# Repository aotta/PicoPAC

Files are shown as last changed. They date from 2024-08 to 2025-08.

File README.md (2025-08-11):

# PicoPAC v.1.0b
Flashcart for Videopac / Odyssey 2 based on Wilco2009 Videopac-microSD card project
Based on SD card by Wilco2009: https://github.com/wilco2009/Videopac-micro-SD-Cart , my greetings for his fantastic job!

Since now, tested on  G-7000, G7400, C52, JOPAC and Odyssey 2. Waiting for a friend that has to repair his G7200 for completing the list ;) 

--changelog v.1.0a ->
Added support to extROM games too (VP_40 and VP_31).
Added filename reading from flash (max files read = 25*8) 

--changelog v.1.0b ->
fixed KTAA final rom

Other info also on Nightfallcrew blog: https://www.nightfallcrew.com/22/09/2024/flash-multicart-for-philips-videopac-magnavox-odyssey-2/

PicoPAC is a multicart DIY yourself based on cheap "PURPLE" Raspberry Pi Pico clone, easy to build and not expensive.
**WARNING!** "purple" Pico has not the same pinout of original Raspberry "green" ones, you MUST use the clone or you may damage your hardware.

**NOTE** You should find all the ROM following this site https://rene-g7400.datatex.nl/ 
Please don't forget to upload the here provided "selectgame.bin" and "selectgame.$$$" file in flash!!!!
Also, even if now you can change filenames, remember that extROM games are checked by name, so they works only if named "VP_31.bin", "VP_40.bin" or "4inarow.bin"!

**NOTE 2** 3D files for shell are WIP and probably the PCB doesn't fit perfectly withous some cut/drill to PCB holes!! (Thanks to Mike Wilson for the Logo version)

Added alternate STLs files thanks to kokkiklhs (see https://forums.atariage.com/topic/370606-picopac-a-pico-purple-porting-of-videopac-microsdcard/page/4/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 for further details)

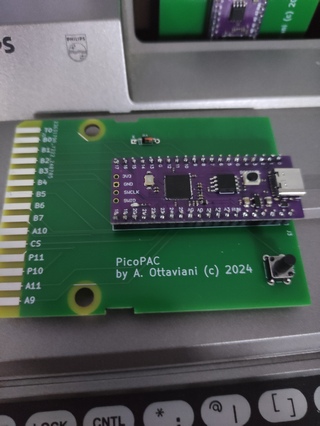
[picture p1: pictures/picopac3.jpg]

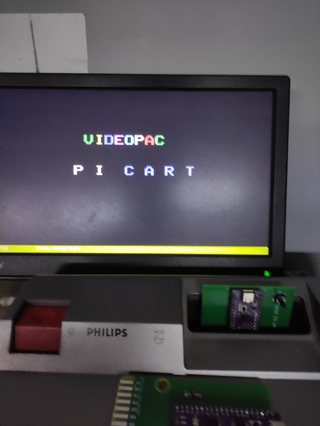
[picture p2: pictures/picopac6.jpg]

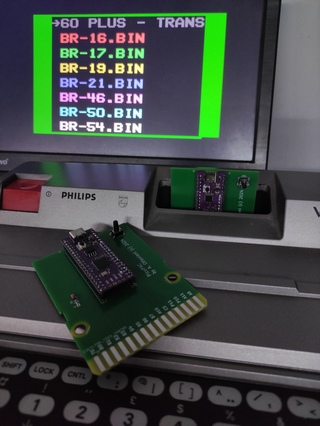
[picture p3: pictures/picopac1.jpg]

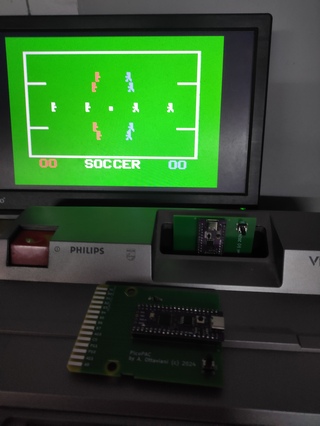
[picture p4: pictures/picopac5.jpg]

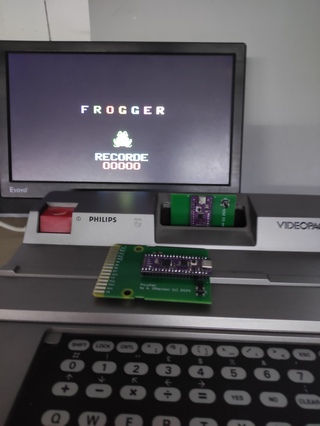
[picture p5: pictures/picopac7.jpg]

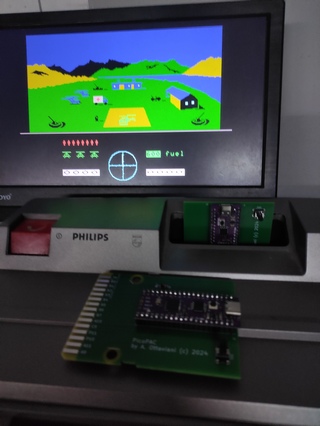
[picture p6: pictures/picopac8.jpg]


Kicad project and gerbers files for the pcb are in the PCB folder, you need only a diode and a push buttons for resetting the cart if needed or want restart. 
Add you pico clone, and flash the firmware ".uf2" in the Pico by connecting it while pressing button on Pico and drop it in the opened windows on PC.
After flashed with firmware, and every time you have to change your ROMS repository, you can simply connect the Pico to PC and drag&drop "BIN" files  into.
But remember that only games already in menu will be seen by the cart.

Even if the diode should protect your console, **DO NOT CONNECT PICO WHILE INSERTED IN A POWERED ON CONSOLE!**

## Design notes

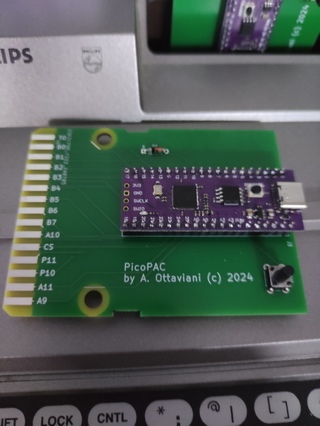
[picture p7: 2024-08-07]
pictures/picopac4.jpg

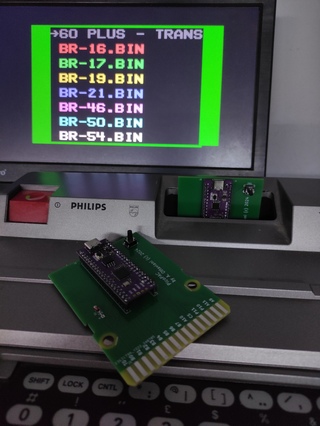
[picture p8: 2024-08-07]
pictures/picopac2.jpg

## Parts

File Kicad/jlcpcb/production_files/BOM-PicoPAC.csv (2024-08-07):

Comment | Designator | Footprint | LCSC
Conn_01x20 | J3 | PinSocket_1x20_P2.54mm_Vertical
Conn_01x20 | J2 | PinSocket_1x20_P2.54mm_Vertical
SW_Push | SW1 | SW_PUSH_6mm
Diode | D1 | D_DO-35_SOD27_P7.62mm_Horizontal
Videopac-edgeconnector | J1 | videopac-edgecon

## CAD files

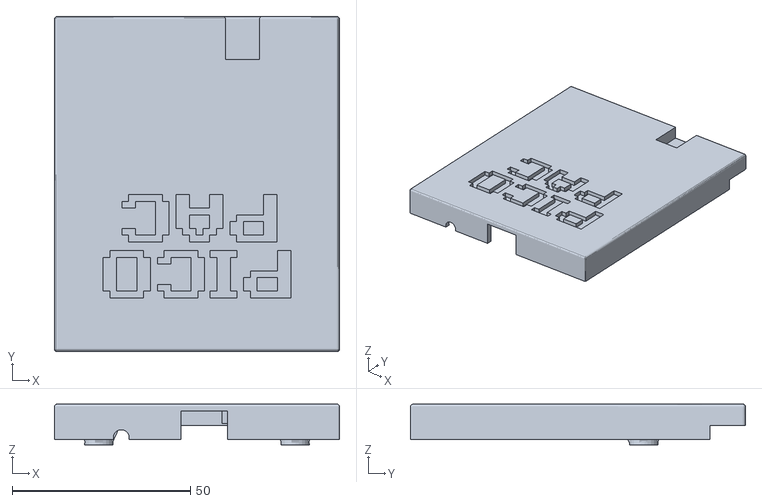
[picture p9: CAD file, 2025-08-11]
3dPrint/Alternate/PicoPAC_1.stl
80.0 x 94.0 x 11.5

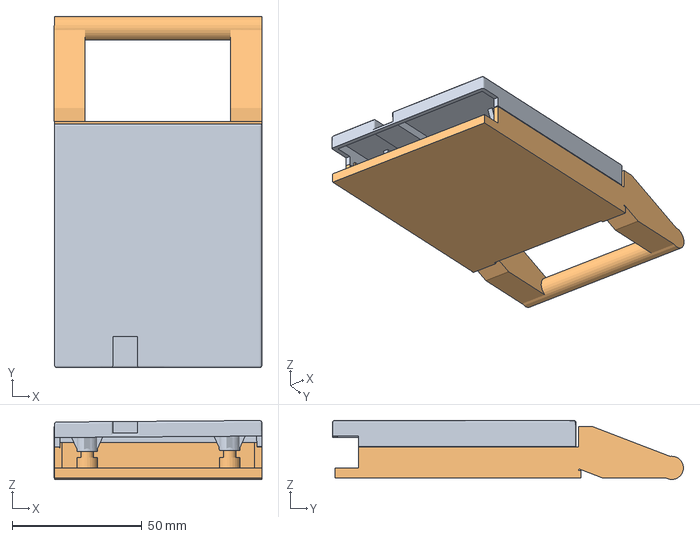
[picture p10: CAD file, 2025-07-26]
3dPrint/PicoPAC.FCStd
80.3 x 135.5 x 22.8 mm
PicoPAC_top-Cover (Meshed)
Base (Meshed)

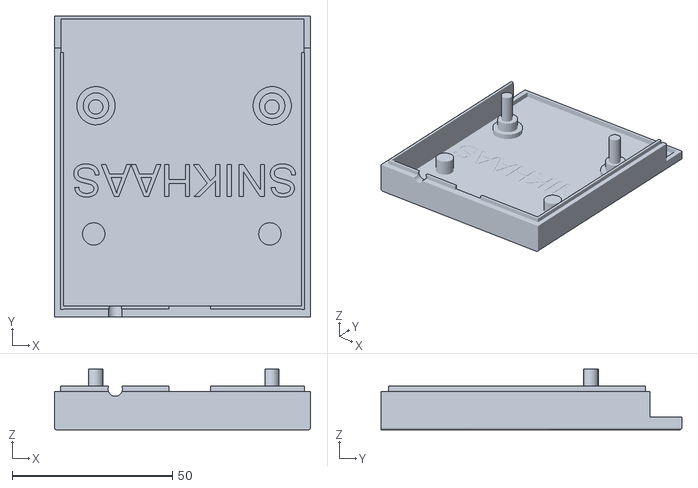
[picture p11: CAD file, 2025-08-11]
3dPrint/Alternate/PicoPAC_2.stl
80.0 x 94.0 x 19.0

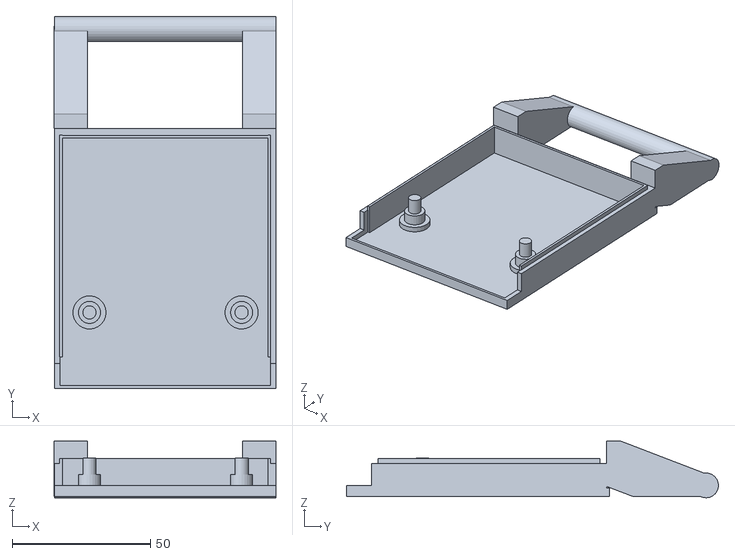
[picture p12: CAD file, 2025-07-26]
3dPrint/PicoPAC-Base (Meshed).stl
80.2 x 134.5 x 20.5

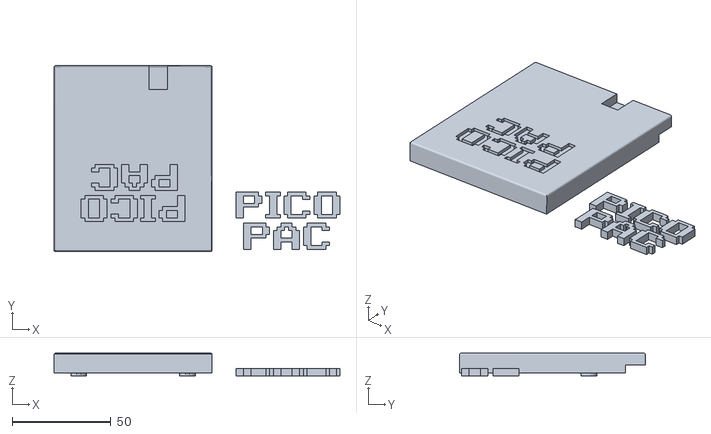
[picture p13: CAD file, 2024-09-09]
3dPrint/o2picocartlogo2.stl
144.7 x 94.0 x 11.5

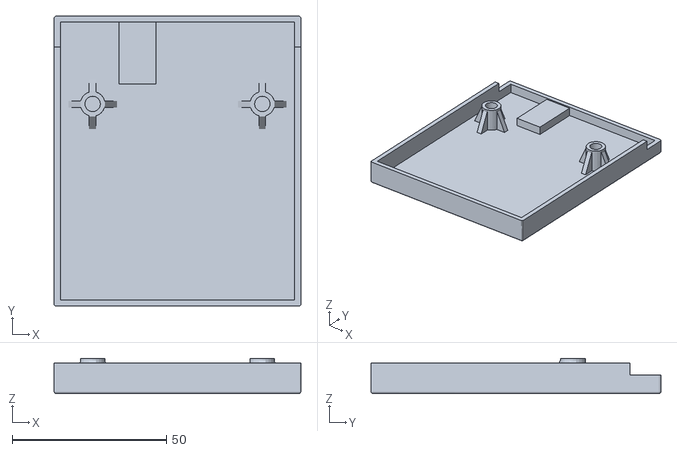
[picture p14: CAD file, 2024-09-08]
3dPrint/PicoPAC_top-Cover (Meshed).stl
80.0 x 94.0 x 11.5

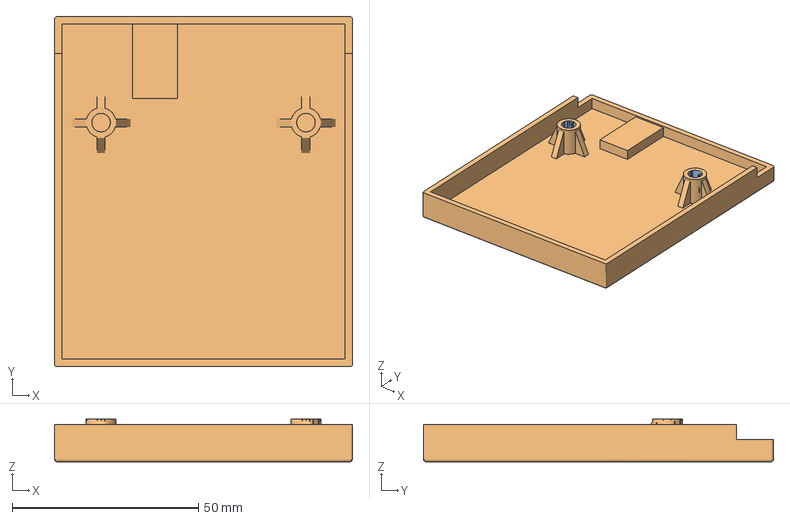
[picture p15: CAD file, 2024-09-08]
3dPrint/PicoPAC_top.FCStd
80.0 x 94.0 x 11.5 mm
Cover
Cover (Meshed)

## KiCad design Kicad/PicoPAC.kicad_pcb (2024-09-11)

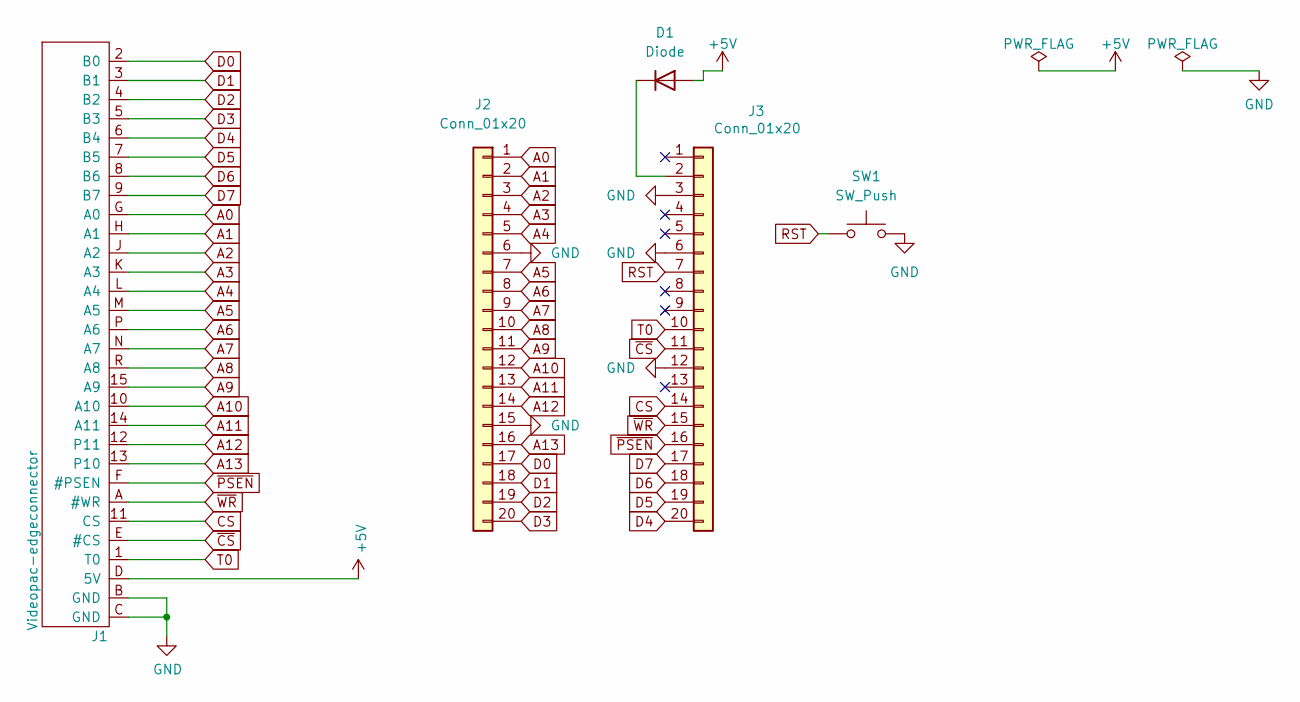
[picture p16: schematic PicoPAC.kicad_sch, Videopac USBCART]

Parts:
D1: Diode; D_DO-35_SOD27_P7.62mm_Horizontal
J1: Videopac-edgeconnector; videopac-edgecon
J2, J3: Conn_01x20; PinSocket_1x20_P2.54mm_Vertical
SW1: SW_Push; SW_PUSH_6mm

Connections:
+5V: D1.2 (A), J1.D (5V)
A0: J1.G (A0), J2.1
A1: J1.H (A1), J2.2
A2: J1.J (A2), J2.3
A3: J1.K (A3), J2.4
A4: J1.L (A4), J2.5
A5: J1.M (A5), J2.7
A6: J1.P (A6), J2.8
A7: J1.N (A7), J2.9
A8: J1.R (A8), J2.10
A9: J1.15 (A9), J2.11
A10: J1.10 (A10), J2.12
A11: J1.14 (A11), J2.13
A12: J1.12 (P11), J2.14
A13: J1.13 (P10), J2.16
CS: J1.11 (CS), J3.14
D0: J1.2 (B0), J2.17
D1: J1.3 (B1), J2.18
D2: J1.4 (B2), J2.19
D3: J1.5 (B3), J2.20
D4: J1.6 (B4), J3.20
D5: J1.7 (B5), J3.19
D6: J1.8 (B6), J3.18
D7: J1.9 (B7), J3.17
GND: J1.B (GND), J1.C (GND), J2.6, J2.15, J3.3, J3.6, J3.12, SW1.2
unnamed: D1.1 (K), J3.2
RST: J3.7, SW1.1
T0: J1.1 (T0), J3.10
~CS: J1.E (#CS), J3.11
~PSEN: J1.F (#PSEN), J3.16
~WR: J1.A (#WR), J3.15

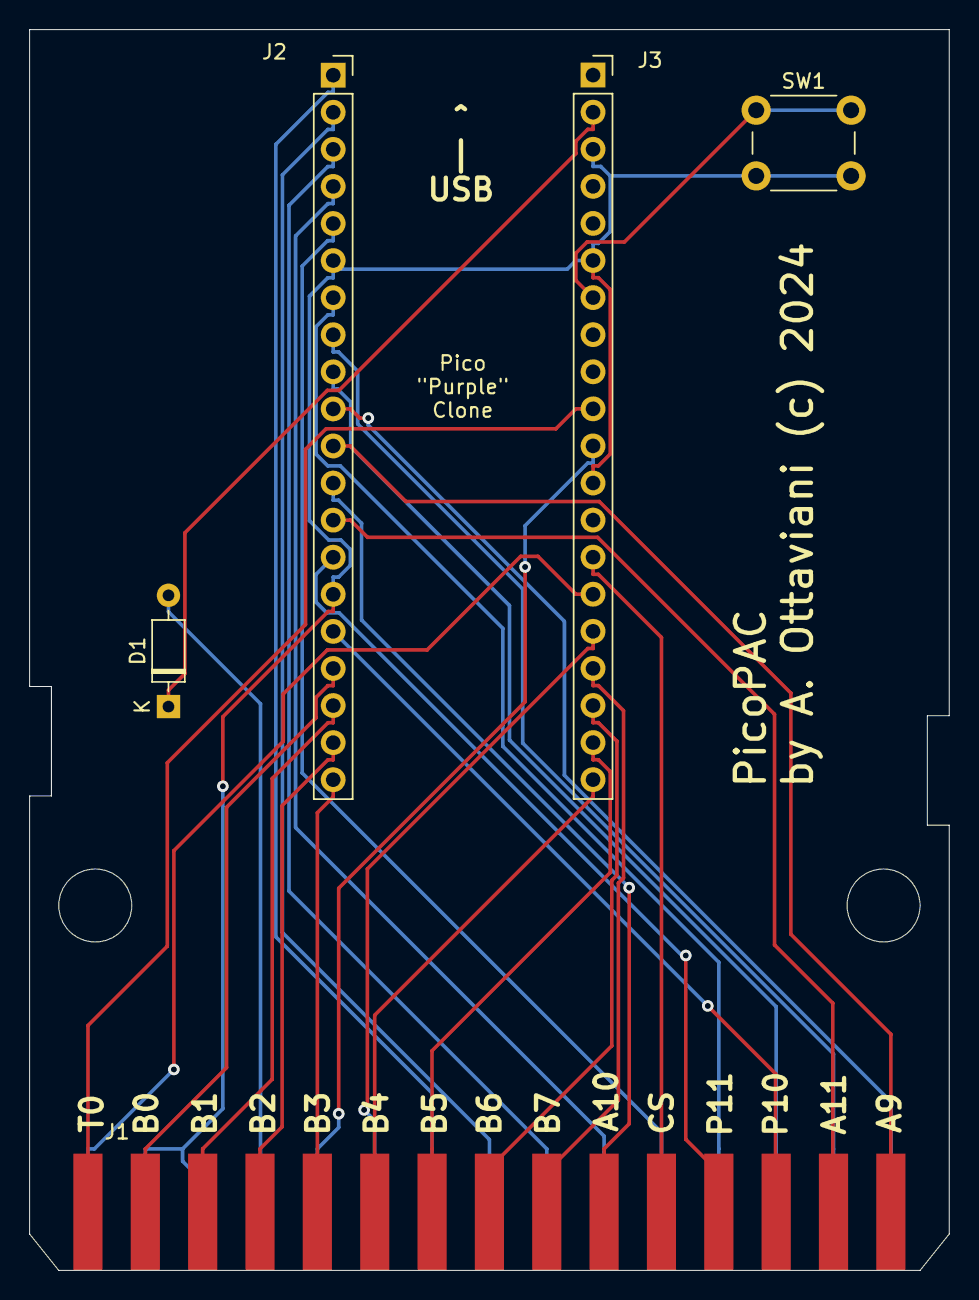
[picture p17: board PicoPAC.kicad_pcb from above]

Board: 2 copper layers, 63.0 x 85.0 mm, 5 parts (0 on the bottom side), 31 nets.

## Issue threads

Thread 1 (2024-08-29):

Garbled screen on O2 with Voice attached

MrSeven-LV, 2024-08-29:
I get nothing but random Odyssey characters when I attempt to use this on an Odyssey 2 with The Voice module attached. When I remove The Voice, the menu shows up and I can scroll through all the games. I was only able to load and play Smithereens. Any attempt to load any other game results in the menu locking up. All ROMs were acquired from the site recommended and they all reside in the root directory of the Pi.

aotta, 2024-08-30:
Some incompatibility with Voice is known even for the original microsdcart, i haven't it so i can't troubleshooting or fix it.
About issue with all games but one, i didn't tested the cart with a ntsc O2 but it should work same way of Videopac. please check that filenames of rom in flash match with list in filelist.h (and just found a mistake in line 48! 😂 ), and please report what if you press reset, and if pico blinks with an error code, and in case how many flashes you got .

MrSeven-LV, 2024-08-30:
No worries on my game loading problem, it was my fault. After I saw that it wasn't working with The Voice, I re-flashed it, got side tracked for a while and completely forgot that I didn't copy all the ROMs back. It works great just like all your other Pico carts. I feel silly now.

Understood on The Voice incompatibility. My O2 looks naked without it. 😂

I don't know if there is a difference in the way the PCB mounts in a Videopac cartridge, but in order to fit it inside an O2 cartridge shell, I had to increase the size of the notches about 4-5mm. No big deal, it fits perfect.

Thanks for the quick response, all my issues have been taken care of. Great work BTW. Now where are those 2600 and 5200 Pico carts? 😂

aotta, 2024-08-30:
Happy you solved, i hope one day to get a Voice (i read about a sort of adapter for Videopac on a forum) and solve the incompatibiliry with PicoPAC.
I don't have a 5200 so no plan for a flashcart for it, but Pico2600 is one of the next on my todo list... stay tuned! ;)

PhilDPino, 2025-01-01:
Came here to see if a solution was found for the Voice incompatibility? Is it a shell fitting/notch issue or a firmware update needed?

PhilDPino, 2025-01-01:
Also would be interested in a 5200 Pico

aotta, 2025-01-01:
Not yet got a The Voice nor an Atari 5200 to work on them.
If you want to donate them to me i remain available ;)

Closed 2024-08-30.

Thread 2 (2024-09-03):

Does not work on G7000

Ahnl66, 2024-09-03:
Hi, I built the card, and I think hardware is OK. But when I run it in the G7000 it starts with garbled screen. When I press reset, I do see the pi pac screen, and next it is garbled again.  I did try a couple of things:
- I renamed a game to select game.bin, and indeed it looks like the game starts when I startup the console, but the game is corrupt and doesn't work.
- I recompiled the VSC-PicoPac and flashed Pico again, did not help. In picopac_cart.c I changed the set_sys_clock_khz to 179000 and also to 360000 - did not help
- i deleted all files, except for selectgame.bin. Then there is only a garbled screen, the reset does not do anything.

My conclusions so far
- hardware seems OK. Otherwise I think it would not work at all
- selectgame.bin is OK. Otherwise when I renamed a game to selectgame.bin, it would work
- So I think problem is in VSC-PicoPac, and likely something with reading the filesystem. It seems when loading a file from disk the wrong sectors/data is read
- Strange thing is that when I start up the console, immediately screen is garbled. And only when I press reset the pi pac screen appears, so it seems to skip something at boot.

Any clue what I could try next?

PS: I do not need to put ALL te files on the pico, I put on the vp ones and the selectgame.bin. Or do I need to put everything on?

Thanks for a great project!

Arthur

https://github.com/user-attachments/assets/9c502dd6-ab86-492e-9e40-31276e60a1a2

moparisthebest, 2024-09-05:
My North American Odyssey 2 behaves the exact same way with this cart

aotta, 2024-09-05:
Uploaded new uf2 and selectgame.bin that should work with G7000

Ahnl66, 2024-09-05:
Thanks so much - it works! Very interested to understand the fixes you made, would be great if you could update the code in git so I can learn.

aotta, 2024-09-05:
Yes i just fixed the VP_31 and VP_40 XROM games that didn't work. I'll update all in few minutes

Closed 2024-09-05.

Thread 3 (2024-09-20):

Jet25-Radiola no menu on screen on boot

repetto74, 2024-09-20:
Hello Aotta,

I have built this nice PicoPAC for a JET25 made by Radiola (should be the french version of the C25 tested working).

I programmed the Pico with latest firmware then added the Select Game.bin and a set of bin roms taken from the link you provided.
Unfortunately I just do not reach the menu screen but I'll get the messy screen when a cart is not inserted.
This JET25 is of course working with original carts.
The green led of the Pico flashes 2 times in a loop.
What could be wrong here?
Thanks in advance for any valuable suggestion :-)
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

repetto74, 2024-09-20:
Just a quick comment. The OS is indeed in french so do not know how much this can interfere with the Pico firmware. Maybe I need to rename the Select Game.bin? Just a blind guess.

aotta, 2024-09-20:
Read twice the notes on readme, you must upload both .bin and .$$$ files

Il ven 20 set 2024, 12:48 repetto74 ***@***.***> ha scritto:

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

aotta, 2024-09-20:
No issue

repetto74, 2024-09-20:
Thanks indeed I missed the $$$ file. All is working now :-).

Closed 2024-09-20.

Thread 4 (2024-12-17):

Writing more then +/_ 178 roms to root gives write error

snikhaas, 2024-12-17:
Hi,

I was trying to add extra roms to the root of the picopac  , but notices that it gives me write errors when there are more then 178-ish roms in the root..
Can copy extra files in a sub dir, but those are not available in pico pac menu...

Is this a fat limitation or something that can be fixed in a future fw update ?

Ps,  I modified the 3D case and added holes for  reset and usb-c...
I made it available on thingiverse... if not allowed please let now, dont want to step on anyones toes ...and feel free to ad the files to this project.
All credits to original designer..

https://www.thingiverse.com/thing:6864410

aotta, 2024-12-18:
Most of the filelist structure is "hardcoded" in selectgame.bin, i modified the original one by Wilco a bit, but supporting more files or subfolder management would imply a total rewriting of the selectgame that's out of my scope

snikhaas, 2024-12-18:
Thanks for getting back to me. 👍🏻

Now I know there's nothing wrong with my pi zero clone..

Have a nice day.

Best regards

Closed 2024-12-18.

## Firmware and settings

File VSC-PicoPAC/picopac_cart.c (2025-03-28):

/*
//                       PicoPAC MultiCART by Andrea Ottaviani 2024
//
//  VIDEOPAC  multicart based on Raspberry Pico board -
//
//  More info on https://github.com/aotta/ 
//
//   parts of code are directly from the A8PicoCart project by Robin Edwards 2023
//  
//   Needs to be a release NOT debug build for the cartridge emulation to work
// 
//   Edit myboard.h depending on the type of flash memory on the pico clone//
//
//   v. 1.0 2024-08-05 : Initial version for Pi Pico 
//
*/


#include <stdio.h>
#include <stdlib.h>
#include <string.h>
#include "pico/multicore.h"
#include "hardware/gpio.h"
#include "pico/platform.h"
#include "pico/stdlib.h"
#include "hardware/vreg.h"
#include "pico/divider.h"
#include "hardware/flash.h"
#include "hardware/sync.h"


#include "tusb.h"
#include "ff.h"
#include "fatfs_disk.h"

// Pico pin usage definitions

#define A0_PIN    0
#define A1_PIN    1
#define A2_PIN    2
#define A3_PIN    3
#define A4_PIN    4
#define A5_PIN    5
#define A6_PIN    6
#define A7_PIN    7
#define A8_PIN    8
#define A9_PIN    9
#define A10_PIN  10
#define A11_PIN  11
#define P11_PIN  12
#define P10_PIN  13
#define D0_PIN   14
#define D1_PIN   15
#define D2_PIN   16
#define D3_PIN   17
#define D4_PIN   18
#define D5_PIN   19
#define D6_PIN   20
#define D7_PIN   21
#define PSEN_PIN 22
#define WR_PIN 23
#define CS_PIN 24   // P14
#define LED_PIN  25 
#define NOTCS_PIN  26 
#define TD_PIN  27 

// Pico pin usage masks
#define A0_PIN_MASK     0x00000001L //gpio 0
#define A1_PIN_MASK     0x00000002L
#define A2_PIN_MASK     0x00000004L
#define A3_PIN_MASK     0x00000008L
#define A4_PIN_MASK     0x00000010L
#define A5_PIN_MASK     0x00000020L
#define A6_PIN_MASK     0x00000040L
#define A7_PIN_MASK     0x00000080L
#define A8_PIN_MASK     0x00000100L
#define A9_PIN_MASK     0x00000200L
#define A10_PIN_MASK    0x00000400L
#define A11_PIN_MASK    0x00000800L
#define P11_PIN_MASK    0x00001000L  // P11 high bank select
#define P10_PIN_MASK    0x00002000L  // P10 low bank select
#define D0_PIN_MASK     0x00004000L //gpio 14
#define D1_PIN_MASK     0x00008000L
#define D2_PIN_MASK     0x00010000L
#define D3_PIN_MASK     0x00020000L
#define D4_PIN_MASK     0x00040000L
#define D5_PIN_MASK     0x00080000L  // gpio 19
#define D6_PIN_MASK     0x00100000L
#define D7_PIN_MASK     0x00200000L
#define PSEN_PIN_MASK   0x00400000L //gpio 22
#define WR_PIN_MASK     0x00800000L //gpio 23  
#define CS_PIN_MASK     0x01000000L //gpio 24   - P14  
#define LED_PIN_MASK    0x02000000L //gpio 25   
#define NOTCS_PIN_MASK  0x04000000L //gpio 26  
#define TD_PIN_MASK     0x08000000L //gpio 27 

// Aggregate Pico pin usage masks
#define ALL_GPIO_MASK  	0x0FFFFFFFL
#define BUS_PIN_MASK    0x00003FFFL
#define BANK_PIN_MASK   0x00003000L
#define DATA_PIN_MASK   0x003FC000L
#define FLAG_MASK       0x0FC00000L
#define ALWAYS_IN_MASK  (BUS_PIN_MASK | FLAG_MASK)
#define ALWAYS_OUT_MASK (DATA_PIN_MASK )

#define SET_DATA_MODE_OUT   gpio_set_dir_out_masked(DATA_PIN_MASK)
#define SET_DATA_MODE_IN    gpio_set_dir_in_masked(DATA_PIN_MASK)
#define SET_LED_ON    	gpio_init(PICO_DEFAULT_LED_PIN);(PICO_DEFAULT_LED_PIN,GPIO_OUT);gpio_put(PICO_DEFAULT_LED_PIN,true);
#define SET_LED_OFF    	gpio_init(PICO_DEFAULT_LED_PIN);gpio_set_dir(PICO_DEFAULT_LED_PIN,GPIO_OUT);gpio_put(PICO_DEFAULT_LED_PIN,false);

// We're going to erase and reprogram a region 256k from the start of flash.
// Once done, we can access this at XIP_BASE + 256k.


char RBLo,RBHi;
char gamelist[255][32];
#define BINLENGTH  1024*128+1
unsigned char rom_table[8][4096];
unsigned char new_rom_table[8][4096];
unsigned char extROM[1024];
unsigned char RAM[1024];
unsigned char files[256*255] = {0};
unsigned char nomefiles[32*25] = {0};
char curPath[256] = "";
char path[256];
volatile char cmd=0;
char errorBuf[40];
bool cmd_executing;
volatile int bankswitch;
int bksw=0;
int romsize;
int lastpos;
volatile u_int8_t bank_type=1;
volatile u_int8_t new_bank_type=1;
volatile char gamechoosen=0;
volatile char newgame=0;
char extram[0xff];


////////////////////////////////////////////////////////////////////////////////////
//                     Error(N)
////////////////////////////////////////////////////////////////////////////////////
void error(int numblink){
 	multicore_lockout_start_blocking();	
    sleep_ms(1000);
	gpio_init(PICO_DEFAULT_LED_PIN);
	gpio_set_dir(PICO_DEFAULT_LED_PIN,GPIO_OUT);
  while(1){

    for(int i=0;i<numblink;i++) {
      gpio_put(PICO_DEFAULT_LED_PIN,true);
      sleep_ms(600);
      gpio_put(PICO_DEFAULT_LED_PIN,false);
      sleep_ms(500);
    }
  sleep_ms(2000);
  }
}

/*
 Theory of Operation
 -------------------
 //
 //
 //
*/
#pragma GCC push_options
#pragma GCC optimize ("O3")
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

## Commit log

2024-09-05 Add files via upload
    fixed ram location for G-7000 compatibility, added exROM (game VP31 e VP40) support
    [picopac_cart.c]
2024-09-09 Update README.md
    added note for 3d stl files
2024-09-11 Add files via upload
    a couple of tracks moved
    [PicoPAC.kicad_pcb]
2024-10-28 Delete 3dPrint/Shell PirtoII Eskimo version directory
    wrong repo
    [PiRTO_II-Cart-Bottom+Logo.stl, PiRTO_II-Cart-Top.stl]
2025-03-28 new 1.0b version
    fixed KTAA final rom
    [picopac_cart.c]
2025-07-26 Add files via upload
    moved a little the pillars to better fitting
    [PicoPAC-Base (Meshed).stl]
2025-07-26 Add files via upload
    little move to pillars for better fitting
    [PicoPAC.FCStd]
2025-08-11 Add files via upload
    Alternate shell by Kokkiklhs
    [PicoPAC_1.stl, PicoPAC_2.stl]

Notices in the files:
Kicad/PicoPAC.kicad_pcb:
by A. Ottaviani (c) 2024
